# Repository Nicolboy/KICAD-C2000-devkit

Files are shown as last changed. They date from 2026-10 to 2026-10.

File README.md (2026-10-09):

# KICAD-C2000-devkit

Shield d'isolation et cartes devkit pour TMS320 C2000, conçus sous KiCad 10.
Le brochage est décrit en Markdown, les symboles et les projets KiCad en sont
**générés** — le document reste la source de vérité, pas le schéma.

Cible : une commande numérique de convertisseur de puissance isolé, pilotée par
un C2000 et supervisée par un ESP32-C6 pour le Wi-Fi et la mise à jour FOTA.

<p align="center">
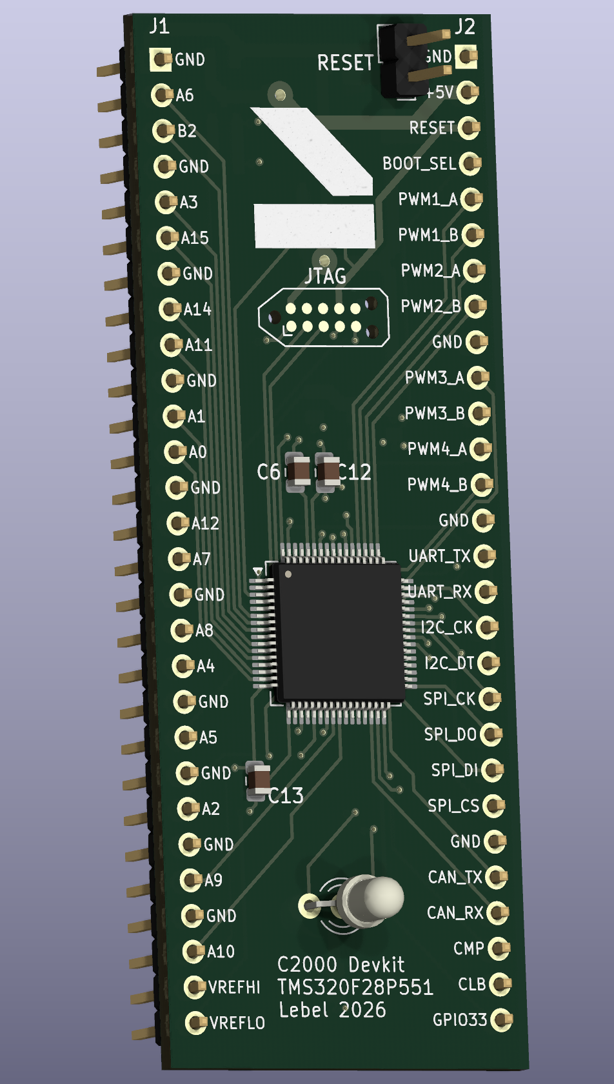
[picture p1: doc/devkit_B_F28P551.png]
Rendu 3D de la carte Devkit TMS320F28P551-LQFP64
  
</p>

---

## Architecture — quatre cartes, une barrière

| Carte | Rôle |
|---|---|
| **Puissance** | Conversion, barrière d'isolation, isolateurs (AMC0311S, AMC0300R, ISO7710, DPC817), shunts en connexion Kelvin, régulateurs |
| **Shield** | Support mécanique des deux devkits, adaptation de brochage, conditionnement analogique, protections. **Aucun composant isolé** |
| **Devkit C2000** | MCU, deux LDO 3,3 V, JTAG, bouton reset, LED, cavalier de boot |
| **Devkit ESP32** | Wi-Fi, hôte FOTA, écran OLED en SPI |

L'isolation est entièrement confinée à la carte de puissance. Le shield ne fait
que du conditionnement côté froid : c'est ce qui permet de le fabriquer en
2 couches à la maison sans se poser de question de ligne de fuite.

Liaison shield ↔ puissance : quatre nappes 2 × 8 à **alternance signal / masse
stricte 1:1**, aucune alimentation dedans. Le +5 V passe par un connecteur
séparé — les 500 mA de la commande n'ont pas à partager leur retour avec les
masses de référence des voies ADC.

---

## Le point de conception le plus notable

**Le connecteur est identique à 100 % entre le F280037 et le F28P551**, 56
positions sur 56. Les deux devkits sont interchangeables sur le shield.

Ce n'est pas une coïncidence, c'est le résultat d'un arbitrage : les LED ont été
délibérément posées sur les **entrées/sorties non communes** aux deux boîtiers,
pour que toutes les broches qui traversent le connecteur, elles, soient
communes. Les quatre divergences restent locales à la carte devkit :

| Broche | F280037 | F28P551 |
|---|---|---|
| 27 | VDD 1,2 V | LED bleue (GPIO20) |
| 28 | VDDIO 3,3 V | LED rouge (GPIO21) |
| 40 | LED rouge (GPIO32) | pastille de test |
| 46 | LED bleue (GPIO39) | VREGENZ à VSS |

La cause profonde est le régulateur 1,2 V : le F28P551 a le sien en interne,
activé par VREGENZ à VSS ; le F280037 en 64 PM non-Q n'a pas cette broche et
demande un LDO supplémentaire.

---

## Le brochage est du code

Le fichier [`doc/spec-devkit.md`](doc/spec-devkit.md) fait autorité. Les
symboles KiCad, les schémas et les vérifications en découlent par génération —
on ne modifie jamais un `.kicad_sym` à la main.

```
doc/spec-devkit.md            source de vérité, relue par un humain
        │
        ├── gen_symbole_mcu.py   → build/C2000_MCU_LQFP64.kicad_sym
        │                          (dimensionne le symbole depuis les noms)
        │
        └── gen_devkit.py        → devkit_A_F280037.*  devkit_B_F28P551.*
              ▲                    kicad_gen.py — primitives communes
              │
            src/*.kicad_sch        schémas source des devkits, versionnés

shield.*                       édité à la main dans KiCad — pas généré
```

L'intérêt n'est pas le gain de temps, c'est que **les règles de conception
deviennent exécutables**. Les générateurs vérifient ce que le document promet :
unicité des broches et des GPIO, masse de part et d'autre des voies de mesure de
courant, présence des réserves. Une divergence entre l'intention et le schéma
est une erreur de script, pas un oubli qu'on découvre au routage.

`gen_symbole_mcu.py` dimensionne par exemple le corps du symbole à partir de la
longueur réelle du nom de broche le plus long, pour que les textes des quatre
faces ne se croisent jamais — plutôt qu'une taille choisie à l'œil qui casse au
premier nom un peu long.

Les schémas ne contiennent d'ailleurs **aucun fil** : toute la connectivité
passe par des étiquettes globales posées sur le point de connexion de chaque
broche. C'est ce qui permet d'ajouter un composant par script sans rien router.

---

## Concevoir avec un agent

Une part inhabituelle du travail est faite par un agent : lire les datasheets,
en extraire les contraintes, écrire la spécification, générer les symboles,
poser les composants et choisir les boîtiers. **Le placement et le routage
restent manuels** — ils encodent des choix que rien ne devine sur une chaîne de
mesure de courant.

[`doc/methode-kicad-claude.md`](doc/methode-kicad-claude.md) documente cette
façon de travailler : le partage des rôles, le déroulé d'une séance, et surtout
les pièges de format rencontrés — chacun avec sa signature, parce que KiCad
répond « échec du chargement » et rien de plus quand un fichier est malformé.

---

## Projets KiCad

Trois, pas un de plus.

| Projet | Contenu |
|---|---|
| `shield.*` | Shield, connecteurs devkit 2 × 28, quatre nappes, ESP32-C6 |
| `devkit_A_F280037.*` | Devkit TMS320F280037CSPM |
| `devkit_B_F28P551.*` | Devkit TMS320F28P551SG5PM |

---

## Reproduire

KiCad 10 et Python 3.12 requis. `kicad-cli` doit être dans le `PATH`.

```bash
python gen_symbole_mcu.py -o build/     # symboles MCU
python gen_devkit.py --force            # les deux projets devkit

kicad-cli sch erc --exit-code-violations <projet>.kicad_sch
kicad-cli pcb drc --exit-code-violations <projet>.kicad_pcb
```

`shield.*` n'apparaît pas ici : il est édité à la main et ne se régénère pas.
Les schémas de devkit produits à la racine sont en revanche **jetables** — toute
retouche manuelle y est perdue au prochain `--force`. Ce qui doit survivre se
modifie dans `src/` ou dans le générateur.

Chaque carte existe en **deux versions de fabrication** : 2 couches gravées à
la maison — pistes 1 mm, vias 2 mm, perçage 0,8 mm — pour itérer vite sur la
mécanique, et 4 couches en fabrication externe, avec plan de masse continu sous
la zone analogique. Même schéma, même brochage, seul le PCB change.

---

## État d'avancement

Travail en cours, et le dire plutôt que de le masquer :

- **Devkit B (F28P551)** — **PCB placé et routé** (24 empreintes, DRC à 0
  violation). Les deux connecteurs 2 × 28 portent désormais une sérigraphie
  par broche — canal ADC réel, GPIO, rôle de bus générique (`I2C_CK`/`DT`,
  `SPI_CK`/`DO`/`DI`/`CS`...) et alimentations, plutôt que les noms
  spécialisés du schéma (`Vin`, `I_SHUNT1_CMP`...), pour que le connecteur se
  lise seul. L'ERC du schéma reste à 41 violations, de la même famille que
  les autres projets (pins de réserve non pilotées).
- **Devkit A (F280037)** — PCB **peuplé** (27 empreintes posées depuis le
  schéma) mais pas encore routé : 106 pastilles non connectées au DRC.
- **Shield** — connecteurs posés, alimentations câblées avec `PWR_FLAG` par
  net. Le routage des signaux n'est pas fait : il demande des choix de
  conception qui n'ont pas leur place dans un générateur. D'où les 108
  violations d'ERC (`pin_not_connected` attendus). PCB non routé.
- **Carte de puissance** — spécifiée dans `doc/`, pas encore dessinée.

Les points laissés ouverts — caractéristiques de sortie des AMC, courant
d'entrée du REFIN, choix de VREFHI — sont listés en fin de
[`doc/decisions.md`](doc/decisions.md). Ils attendent une lecture de datasheet,
pas une estimation.

---

## Décisions à ne pas défaire

Certains choix ressemblent à des inefficacités sans en être. Les douze sont
documentés dans [`doc/decisions.md`](doc/decisions.md), chacun avec sa raison et
ce qui casse si on le défait — entre autres :

- Les **PWM3 et PWM4 restent en réserve et restent des PWM** : ce sont les deux
  seules paires complémentaires HRPWM avec temps mort matériel disponibles.
- Chaque shunt sort **deux fois**, `_MES` filtré et `_CMP` direct. Le chemin
  comparateur attaque le CMPSS sans filtre anti-repliement : pas de retard sur
  le déclenchement de la Trip Zone, et un défaut du filtre ne désarme pas la
  protection.
- Les **16 voies ADC sortent toutes** pour 9 nécessaires, les 5 libres étant
  câblées jusqu'aux réserves de nappe. Une voie ajoutée plus tard se raccorde
  sans retoucher une seule carte.

---

## Licence

[CERN-OHL-S v2](LICENSE) — CERN Open Hardware Licence, fortement réciproque.

Tu peux étudier, modifier, fabriquer et distribuer ce matériel. En contrepartie,
si tu distribues un produit fondé dessus, ou une version modifiée, tu dois
publier les sources correspondantes sous la même licence.

C'est la licence de référence du matériel libre, l'équivalent de la GPL côté
logiciel. Si tu préfères une réciprocité limitée à la carte elle-même, ou pas de
réciprocité du tout, les variantes CERN-OHL-W et CERN-OHL-P existent.

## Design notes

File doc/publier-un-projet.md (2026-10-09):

# Publier un projet sur GitHub — mémo et prompt

Mémo de poste à poste. Ce qui suit vient de pièges réels, pas d'une liste de
bonnes pratiques générales.

---

## Un poste, une clé

**Une clé privée ne voyage pas.** Copiée sur une clé USB ou envoyée par
messagerie, elle devient une copie qu'on ne contrôle plus, et on perd la
capacité de révoquer un seul poste sans casser les autres.

GitHub accepte autant de clés de compte que l'on veut. Sur un nouveau poste :

```bash
ssh-keygen -t ed25519 -C "contact@nicolasboyer.fr" -f ~/.ssh/github_<poste>
cat ~/.ssh/github_<poste>.pub        # à coller sur github.com/settings/keys
```

Puis dans `~/.ssh/config` :

```
Host github.com
    HostName github.com
    User git
    IdentityFile ~/.ssh/github_<poste>
    IdentitiesOnly yes
```

**Vérification qui compte** : `ssh -T git@github.com` doit répondre
`Hi Nicolboy!`. S'il répond un **nom de dépôt**, c'est une clé de
*déploiement* — limitée à ce dépôt, et inutilisable ailleurs. Une clé de
déploiement survit d'ailleurs quelque temps à la suppression de son dépôt, et
bloque alors sa propre réutilisation avec un « key already in use » déroutant.

**Piège associé** : un `core.sshCommand` dans le `.git/config` d'un dépôt
court-circuite `~/.ssh/config` et impose une autre clé. Symptôme : `ssh -T`
réussit, `git push` échoue avec « denied to deploy key ».

```bash
git config --local --unset core.sshCommand
```

---

## Prompt de migration

À coller dans Claude Code sur le poste concerné.

```
Je veux publier mes projets de ce poste sur GitHub, compte Nicolboy.
Procède projet par projet, dans cet ordre, et arrête-toi à chaque décision.

1. INVENTAIRE
   Liste les dossiers de projet, leur taille, s'ils sont déjà sous git,
   et ce qu'ils contiennent. Ne touche à rien pour l'instant.
   Dis-moi lesquels te semblent publiables et lesquels ne le sont pas.

2. CE QUI BLOQUE UNE PUBLICATION — vérifie-le avant tout le reste
   - Datasheets et documents constructeur : SOUS COPYRIGHT, jamais
     redistribuables. Cherche tous les PDF, y compris dans l'historique git.
     S'ils sont déjà commités, un `git rm` ne suffit pas : un clone les
     rapatrierait. Il faut purger l'historique.
     À la place, écris un docs/references.md avec les références exactes
     et où les télécharger chez le fabricant.
   - Secrets : clés, jetons, mots de passe, SSID. Cherche aussi dans
     l'historique.
   - Code tiers : SDK, bibliothèques fabricant. Ne les réécris pas et ne
     retire jamais leurs en-têtes de copyright — c'est la condition qui rend
     leur redistribution légale. Dis-moi sous quelle licence ils sont.

3. PRÉPARATION
   - .gitignore : binaires, dossiers de build, config locale d'IDE,
     outillage d'agent (.claude/, .codex/), *.pdf
   - README : ce que fait le projet, son architecture, son ÉTAT RÉEL —
     y compris ce qui ne marche pas encore. Pas de liste de fonctionnalités.
   - LICENSE : demande-moi laquelle. CERN-OHL-S pour du matériel,
     MIT ou Apache-2.0 pour du logiciel.
   - Vérifie que la branche par défaut porte bien le travail à jour.
     Une branche `main` abandonnée pendant que tout vit ailleurs est un
     piège classique : GitHub affiche `main`.

4. AVANT DE POUSSER
   - Commite d'abord tout ce qui traîne non sauvegardé, avec de vrais
     messages qui disent POURQUOI, pas quoi.
   - Fais une sauvegarde : git bundle create ../<nom>.bundle --all
   - Propose-moi un nom de dépôt et attends ma validation.
   - Ne pousse jamais sans me demander.

Règles générales : commite avant toute modification. Si tu trouves une
incohérence entre la documentation et le code, signale-la, ne la corrige
pas d'office.
```

---

## D'où viennent ces points

| Point | Ce qui s'est passé |
|---|---|
| PDF dans l'historique | 13 Mo de documents TI, **95 % du poids** du dépôt firmware. Purgés : 12 Mo → 579 Ko |
| Branche par défaut | `main` figée depuis six semaines pendant que 51 commits vivaient sur `bringup`. GitHub aurait affiché la vieille |
| Commiter d'abord | une modification substantielle non sauvegardée a failli disparaître dans la réécriture d'historique |
| Clé de déploiement | authentifiait, mais refusait de pousser vers un autre dépôt que le sien |
| Licence du code tiers | les fichiers C2000Ware sont sous BSD 3 clauses : redistribuables, **à condition** de garder les en-têtes |

---

## Conventions de nommage

Les dépôts publiés suivent `<OUTIL>-<CIBLE>-<sujet>` :

- `KICAD-C2000-devkit`
- `CCS-C2000-hv-boost`

Un visiteur du profil voit la paire et comprend que l'un est le matériel et
l'autre ce qui tourne dessus. La partie descriptive reste en minuscules avec
des tirets.

**Un nom n'est pas un engagement** : un renommage GitHub conserve l'historique,
les issues et les étoiles, et installe une redirection permanente depuis
l'ancienne URL.

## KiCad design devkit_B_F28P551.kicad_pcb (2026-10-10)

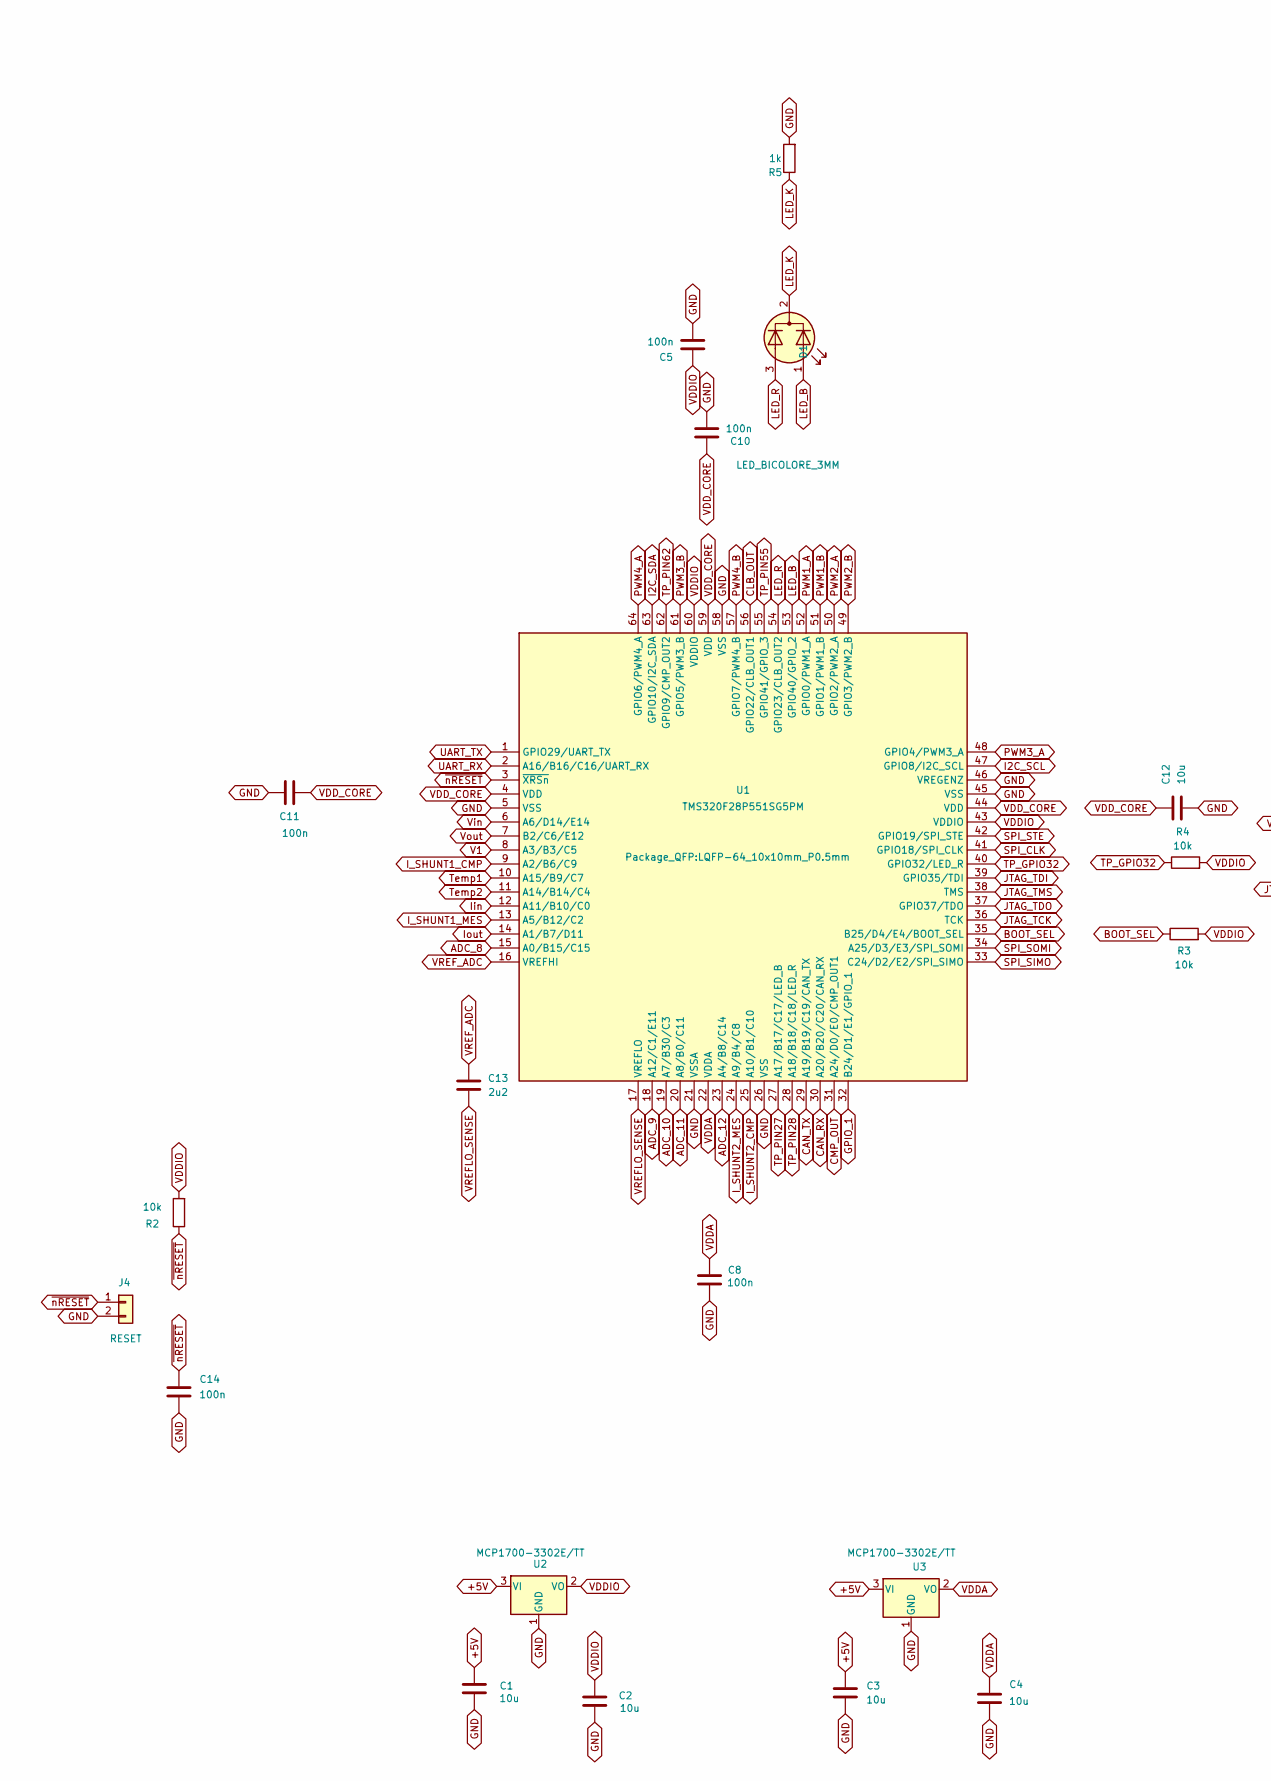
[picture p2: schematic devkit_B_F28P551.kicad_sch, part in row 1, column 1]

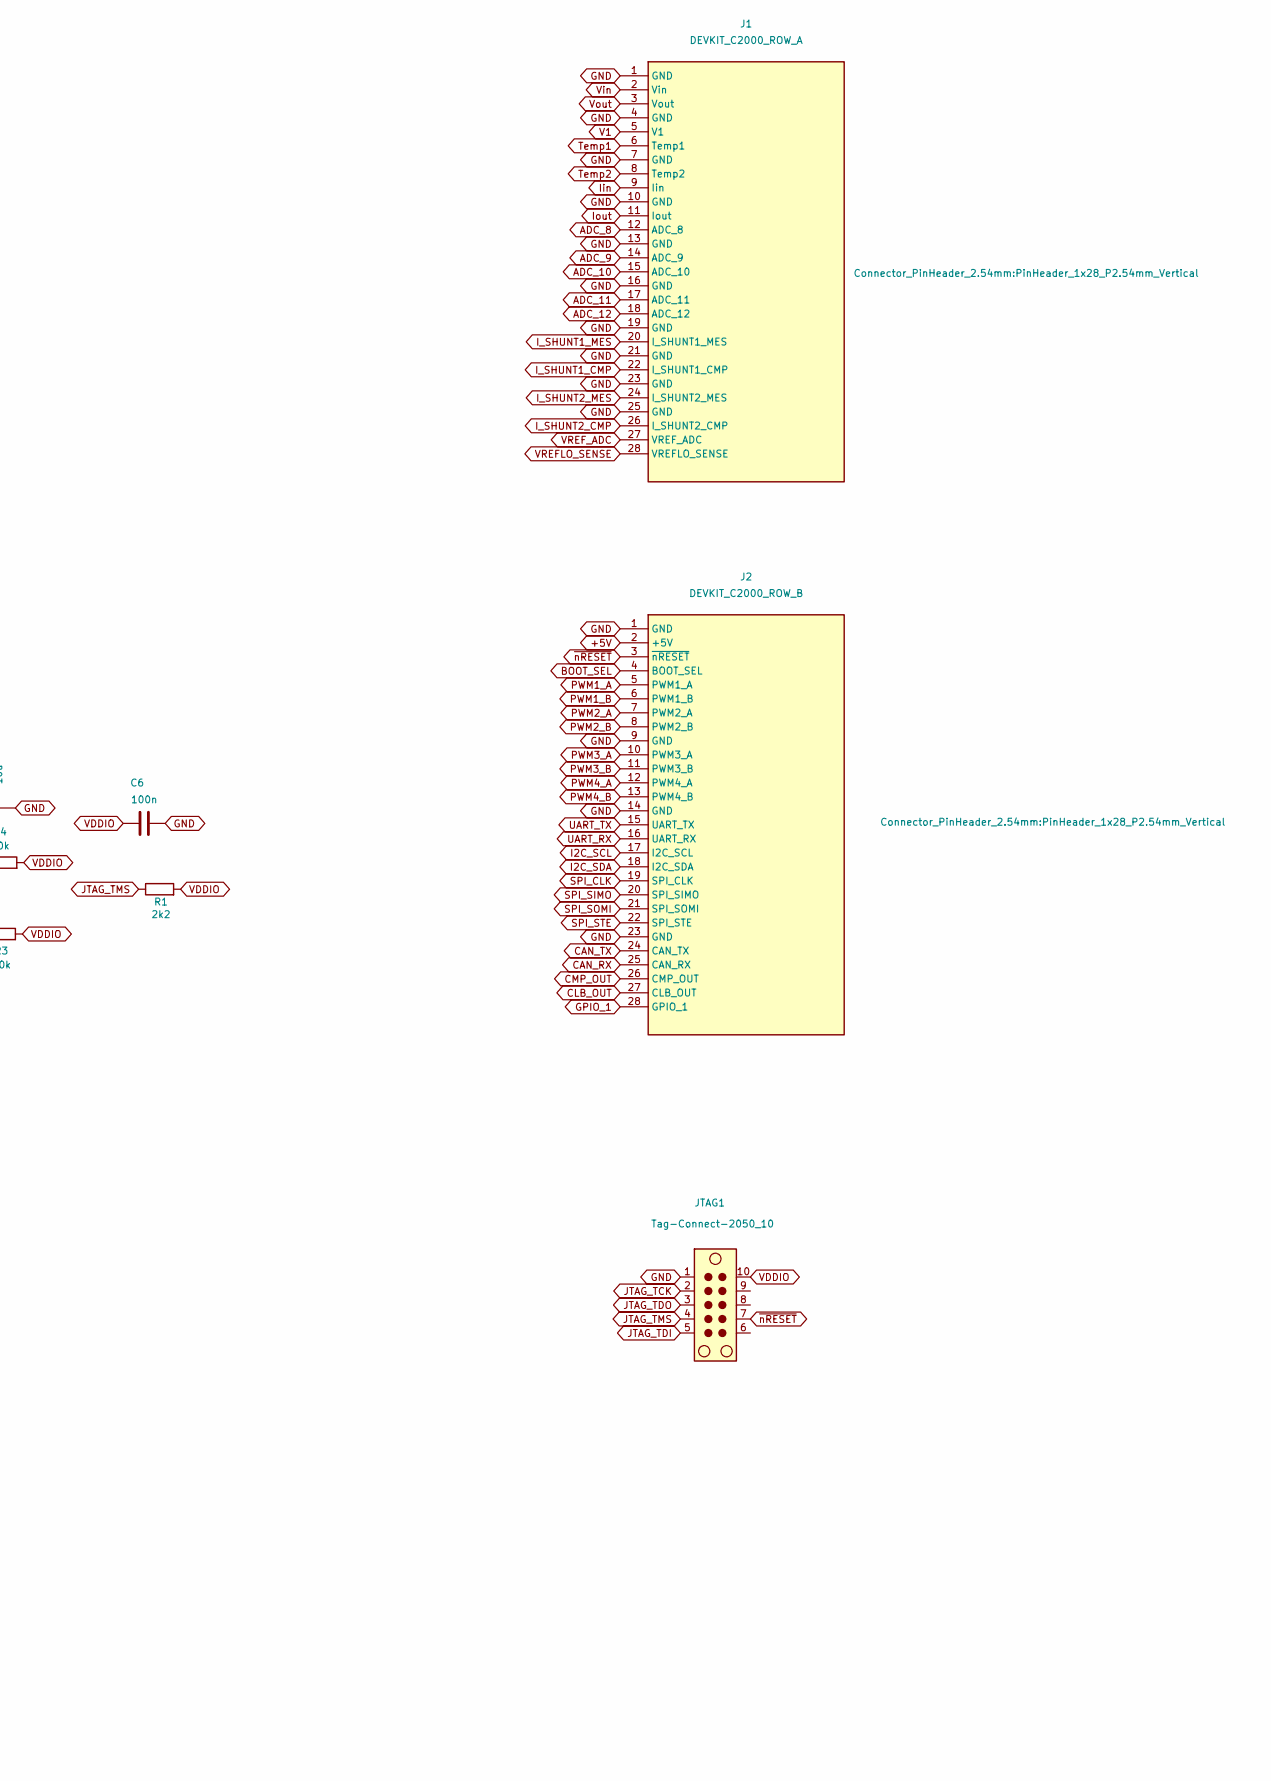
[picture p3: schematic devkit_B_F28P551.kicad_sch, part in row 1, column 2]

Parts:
C1, C2, C3, C4, C12: 10u; C_0805_2012Metric
C5, C6, C8, C10, C11, C14: 100n; C_0805_2012Metric
C13: 2u2; C_0805_2012Metric
D1: LED_BICOLORE_3MM; LED_D3.0mm-3
J1: DEVKIT_C2000_ROW_A; PinHeader_1x28_P2.54mm_Vertical
J2: DEVKIT_C2000_ROW_B; PinHeader_1x28_P2.54mm_Vertical
J4: RESET; PinHeader_1x02_P2.54mm_Vertical
JTAG1: Tag-Connect-2050_10; Tag-Connect_TC2050-IDC-NL_2x05_P1.27mm_Vertical
R1: 2k2; R_0805_2012Metric
R2, R3, R4: 10k; R_0805_2012Metric
R5: 1k; R_0805_2012Metric
U1: TMS320F28P551SG5PM; LQFP-64_10x10mm_P0.5mm
U2, U3: MCP1700-3302E/TT; SOT-23

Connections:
+5V: C1.1, C3.1, J2.2 (+5V), U2.3 (VI), U3.3 (VI)
ADC_8: J1.12 (ADC_8), U1.15 (A0/B15/C15)
ADC_9: J1.14 (ADC_9), U1.18 (A12/C1/E11)
ADC_10: J1.15 (ADC_10), U1.19 (A7/B30/C3)
ADC_11: J1.17 (ADC_11), U1.20 (A8/B0/C11)
ADC_12: J1.18 (ADC_12), U1.23 (A4/B8/C14)
BOOT_SEL: J2.4 (BOOT_SEL), R3.1, U1.35 (B25/D4/E4/BOOT_SEL)
CAN_RX: J2.25 (CAN_RX), U1.30 (A20/B20/C20/CAN_RX)
CAN_TX: J2.24 (CAN_TX), U1.29 (A19/B19/C19/CAN_TX)
CLB_OUT: J2.27 (CLB_OUT), U1.56 (GPIO22/CLB_OUT1)
CMP_OUT: J2.26 (CMP_OUT), U1.31 (A24/D0/E0/CMP_OUT1)
GND: C1.2, C2.2, C3.2, C4.2, C5.2, C6.2, C8.2, C10.2, C11.2, C12.2, C14.2, J1.1 (GND), J1.4 (GND), J1.7 (GND), J1.10 (GND), J1.13 (GND), J1.16 (GND), J1.19 (GND), J1.21 (GND), J1.23 (GND), J1.25 (GND), J2.1 (GND), J2.9 (GND), J2.14 (GND), J2.23 (GND), J4.2, JTAG1.1, R5.2, U1.5 (VSS), U1.21 (VSSA), U1.26 (VSS), U1.45 (VSS), U1.46 (VREGENZ), U1.58 (VSS), U2.1 (GND), U3.1 (GND); also elsewhere on the board
GPIO_1: J2.28 (GPIO_1), U1.32 (B24/D1/E1/GPIO_1)
I2C_SCL: J2.17 (I2C_SCL), U1.47 (GPIO8/I2C_SCL)
I2C_SDA: J2.18 (I2C_SDA), U1.63 (GPIO10/I2C_SDA)
I_SHUNT1_CMP: J1.22 (I_SHUNT1_CMP), U1.9 (A2/B6/C9)
I_SHUNT1_MES: J1.20 (I_SHUNT1_MES), U1.13 (A5/B12/C2)
I_SHUNT2_CMP: J1.26 (I_SHUNT2_CMP), U1.25 (A10/B1/C10)
I_SHUNT2_MES: J1.24 (I_SHUNT2_MES), U1.24 (A9/B4/C8)
Iin: J1.9 (Iin), U1.12 (A11/B10/C0)
Iout: J1.11 (Iout), U1.14 (A1/B7/D11)
JTAG_TCK: JTAG1.2, U1.36 (TCK); also elsewhere on the board
JTAG_TDI: JTAG1.5, U1.39 (GPIO35/TDI); also elsewhere on the board
JTAG_TDO: JTAG1.3, U1.37 (GPIO37/TDO); also elsewhere on the board
JTAG_TMS: JTAG1.4, R1.1, U1.38 (TMS); also elsewhere on the board
LED_B: D1.1 (A1), U1.53 (GPIO40/GPIO_2)
LED_K: D1.2 (K), R5.1
LED_R: D1.3 (A2), U1.54 (GPIO23/CLB_OUT2)
PWM1_A: J2.5 (PWM1_A), U1.52 (GPIO0/PWM1_A)
PWM1_B: J2.6 (PWM1_B), U1.51 (GPIO1/PWM1_B)
PWM2_A: J2.7 (PWM2_A), U1.50 (GPIO2/PWM2_A)
PWM2_B: J2.8 (PWM2_B), U1.49 (GPIO3/PWM2_B)
PWM3_A: J2.10 (PWM3_A), U1.48 (GPIO4/PWM3_A)
PWM3_B: J2.11 (PWM3_B), U1.61 (GPIO5/PWM3_B)
PWM4_A: J2.12 (PWM4_A), U1.64 (GPIO6/PWM4_A)
PWM4_B: J2.13 (PWM4_B), U1.57 (GPIO7/PWM4_B)
SPI_CLK: J2.19 (SPI_CLK), U1.41 (GPIO18/SPI_CLK)
SPI_SIMO: J2.20 (SPI_SIMO), U1.33 (C24/D2/E2/SPI_SIMO)
SPI_SOMI: J2.21 (SPI_SOMI), U1.34 (A25/D3/E3/SPI_SOMI)
SPI_STE: J2.22 (SPI_STE), U1.42 (GPIO19/SPI_STE)
TP_GPIO32: R4.1, U1.40 (GPIO32/LED_R)
TP_PIN27: U1.27 (A17/B17/C17/LED_B)
TP_PIN28: U1.28 (A18/B18/C18/LED_R)
TP_PIN55: U1.55 (GPIO41/GPIO_3)
TP_PIN62: U1.62 (GPIO9/CMP_OUT2)
Temp1: J1.6 (Temp1), U1.10 (A15/B9/C7)
Temp2: J1.8 (Temp2), U1.11 (A14/B14/C4)
UART_RX: J2.16 (UART_RX), U1.2 (A16/B16/C16/UART_RX)
UART_TX: J2.15 (UART_TX), U1.1 (GPIO29/UART_TX)
V1: J1.5 (V1), U1.8 (A3/B3/C5)
VDDA: C4.1, C8.1, U1.22 (VDDA), U3.2 (VO)
VDDIO: C2.1, C5.1, C6.1, JTAG1.10, R1.2, R2.2, R3.2, R4.2, U1.43 (VDDIO), U1.60 (VDDIO), U2.2 (VO); also elsewhere on the board
VDD_CORE: C10.1, C11.1, C12.1, U1.4 (VDD), U1.44 (VDD), U1.59 (VDD)
VREFLO_SENSE: C13.2, J1.28 (VREFLO_SENSE), U1.17 (VREFLO)
VREF_ADC: C13.1, J1.27 (VREF_ADC), U1.16 (VREFHI)
Vin: J1.2 (Vin), U1.6 (A6/D14/E14)
Vout: J1.3 (Vout), U1.7 (B2/C6/E12)
~nRESET: C14.1, J2.3 (~nRESET), J4.1, JTAG1.7, R2.1, U1.3 (~XRSn); also elsewhere on the board

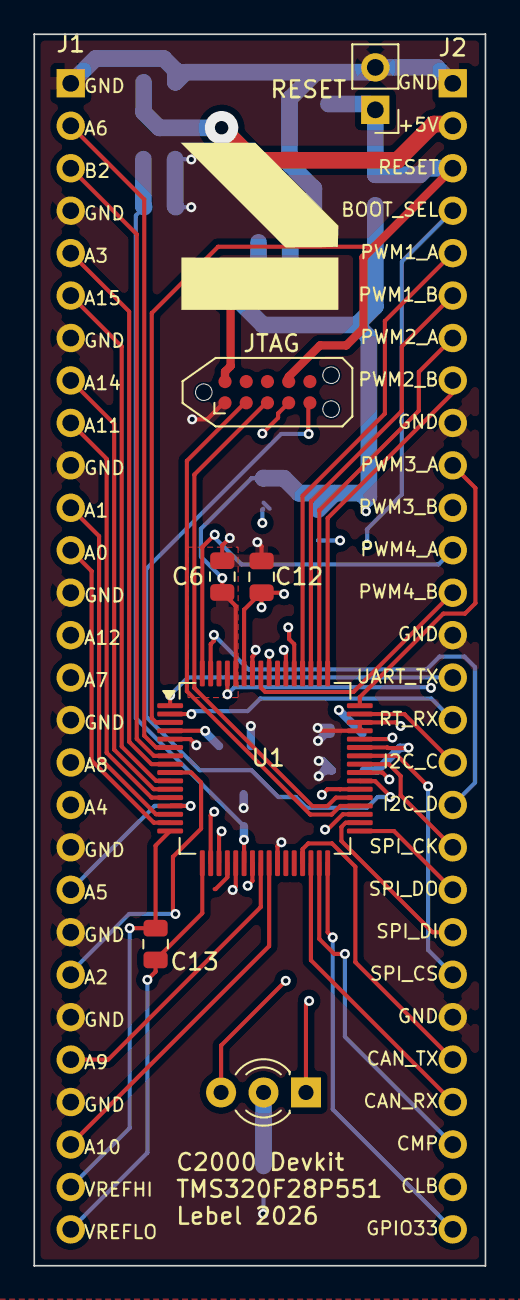
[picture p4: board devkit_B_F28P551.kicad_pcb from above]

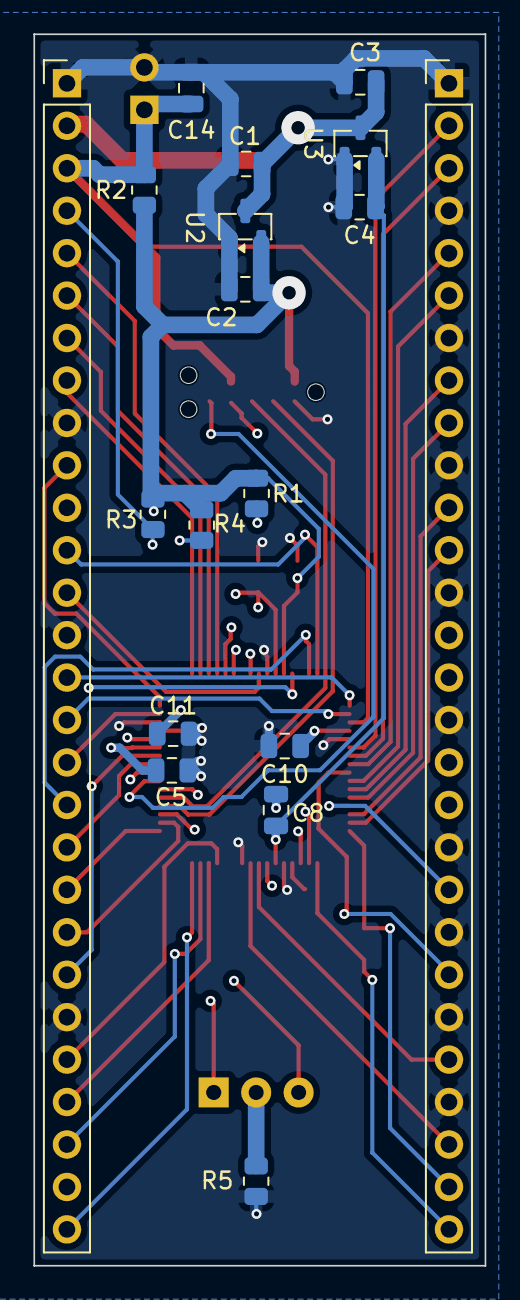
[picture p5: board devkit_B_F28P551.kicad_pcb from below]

Board: 4 copper layers, 27.0 x 73.7 mm, 25 parts (18 on the bottom side), 54 nets.

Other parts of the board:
JTAG: Tag-Connect-2050_10; Tag-Connect_TC2050-IDC-NL_2x05_P1.27mm_Vertical

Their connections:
GND: JTAG.1; also elsewhere on the board
JTAG_TCK: JTAG.2; also elsewhere on the board
JTAG_TDI: JTAG.5; also elsewhere on the board
JTAG_TDO: JTAG.3; also elsewhere on the board
JTAG_TMS: JTAG.4; also elsewhere on the board
VDDIO: JTAG.10; also elsewhere on the board
~nRESET: JTAG.7; also elsewhere on the board

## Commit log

2026-09-28 Memo de publication GitHub, transferable d'un poste a l'autre
    Travailler depuis plusieurs postes demande que ces indications suivent le
    projet plutot que la machine. Le memo rassemble ce qui a reellement coince:
    - une cle privee ne voyage pas: une par poste, ajoutee au compte. Avec le
    symptome qui distingue une cle de deploiement d'une cle de compte, et le
    core.sshCommand local qui court-circuite ~/.ssh/config.
    - le prompt de migration, ordonne, qui fait verifier les bloqueurs AVANT de
    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
2026-10-07 Devkit B routé, sérigraphie des connecteurs 2x28 et logo
    Placement/routage complet du PCB devkit B (24 empreintes, J1/J2 câblés).
    Étiquettes de sérigraphie ajoutées sur les 56 broches des connecteurs
    Row A/Row B (canal ADC réel, GPIO, rôle de bus générique, alimentations)
    via kipy sur l'instance ouverte, plutôt que les noms spécialisés du
    schéma. Logo ajouté (lib/lebel-logo) et fp-lib-table versionné.
    [devkit_B_F28P551.kicad_pcb, devkit_B_F28P551.kicad_sch]
2026-10-07 Corrige le chevauchement silkscreen/cuivre sur UART_RX
    Etiquette raccourcie en RT_RX et clearance JTAG/masse resolue :
    DRC propre (0 violation).
    [devkit_B_F28P551.kicad_pcb]
2026-10-07 Met a jour l'avancement du README par carte
    Devkit B route et DRC propre, sa serigraphie de connecteurs, devkit A
    peuple mais pas route (106 pastilles), shield inchange - chiffres ERC/DRC
    revérifiés sur les trois projets plutot que l'ancien statut global perime.
2026-10-09 Renomme les references au depot (KICAD-C2000-shield -> KICAD-C2000-devkit), suite a jour sur devkit_B_F28P551
    Met a jour CLAUDE.md, README.md et doc/publier-un-projet.md apres le
    renommage du depot GitHub. devkit_B_F28P551.kicad_pcb reflete le travail
    de routage en cours.
    [devkit_B_F28P551.kicad_pcb]
2026-10-10 Ajuste le preset de via a 0.6/0.3mm et resauvegarde le PCB
    Changement de reglage de projet (diametre de via 0.5->0.6mm, meme percage),
    plus la resauvegarde associee du PCB par KiCad (zones de cuivre regenerees).
    [devkit_B_F28P551.kicad_pcb]
2026-10-10 Allege CLAUDE.md : renvoi vers KICAD.md pour ce qui est deja commun
    Coupe les sections dupliquees avec KICAD.md (edition PCB via kipy, schema
    ferme, verification kicad-cli) et avec doc/publier-un-projet.md (cle SSH).
    KICAD.md absorbe les 3 regles qui etaient repetees dans chaque CLAUDE.md
    de projet (commit avant modif, headless, export via kicad-cli uniquement).
2026-10-14 devkit_B_F28P551 : rangee A reroutee pour le CLB (Stage1_EN/Stage2_EN/HV_EN/Discharge), documentation rattrapee
    Carte figee, production-ready, modifiee malgre la regle habituelle (decision
    explicite de l'utilisateur) : miroir de la decision #20 du depot
    KICAD-C2000-powershield cote devkit.
    - Rangee A reroutee : Stage1_EN (A23, broche 62/GPIO9), Stage2_EN (A24,
    broche 27/GPIO20), HV_EN (A25, broche 28/GPIO21), Discharge (A26, broche
    55/GPIO41) - six masses pour vingt-deux signaux au lieu de dix pour
    dix-huit.
    - Rangee B : nRESET -> ~{RESET} (B3), GPIO_1 -> ~{FAULT_MCU} (B28), logique
    negative, meme net.
    - devkit_A_F280037 non modifie (CLB absent du F280037) : le connecteur
    n'est pl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
2026-10-14 Consigne le plan v2 du connecteur devkit (4 connecteurs 1x24, masse en vis-a-vis)
    Proposition non construite, issue de la discussion suite a la decision #13 :
    la rangee A de devkit_B n'a plus que six masses pour vingt-deux signaux. Le
    plan documente la cible (deux connecteurs 1x24 par domaine, dephases
    signal/masse), ce qui reste ouvert (detrompage intra-domaine) et les etapes
    avant de router quoi que ce soit.
2026-10-18 Ajoute le connecteur RKB2SJM250SMTR_LFS et partage TO252
    - Connecteur RKB2SJM250SMTR_LFS (lib + modele 3D) integre au connecteur
    devkit, modification de brochage associee (modificatio_brochage_devkit)
    -- travail deja en place localement, jamais commite.
    - fp-lib-table : empreinte TO252 partagee enregistree
    (lib_fp_commun/TO252.pretty, voir KICAD.md), pas encore utilisee par
    un composant de ce depot.
2026-11-01 Retire le tableau errone des 4 divergences de broches F280037/F28P551
    Le detail (VDD 1,2V/VDDIO/VREGENZ par broche) et l'explication sur le
    regulateur interne etaient faux. Le constat qui reste (connecteur
    identique a 100%, LED posees sur les I/O non communes) est correct.
2026-11-10 Ajoute VDDIO/GND sur J1 broches 47/48, corrige le frein thermique, logo vers lib partagee
    Les deux broches NC du connecteur DEVKIT_C2000_A (47/48) portent
    desormais VDDIO et GND (alternance masse/signal respectee, cote gauche
    GND cote droit signal), pour servir de reference aux pull-up I2C du
    powershield. Meme changement reporte dans la bibliotheque partagee
    C2000_Devkit_Connectors.kicad_sym.
    Corrige aussi 18 erreurs DRC starved_thermal (masses intercalees entre
    signaux sur grille 2,54mm, 1 seul rayon disponible par pastille) en
    abaissant min_resolved_spokes a 1 et min_clearance a 0,5mm.
    Logo lebel bascule vers la bibliotheque partagee lib_fp_commun au lieu
    d'une copie locale.
    Co-Authored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
2026-11-11 README : Devkit B "routé a 100%", decompte des decisions a jour (12->13)
2026-11-11 ERC devkit_B : 10 erreurs -> 0
    - pin_to_pin (2) : broches VDD du MCU typees power_out au lieu de
    power_in dans lib/C2000_MCU.kicad_sym (erreur isolee - VDDA, VDDIO,
    VSS, VSSA etaient deja correctes). Corrige dans la bibliotheque
    source + cache embarque devkit_B ; cache embarque devkit_A
    resynchronise aussi (meme bibliotheque, meme erreur sur ses propres
    VDD) pour eviter un nouveau lib_symbol_mismatch - ERC complet de
    devkit_A pas refait, hors perimetre de cette demande.
    - power_pin_not_driven (3, dont VDD_CORE revele par le fix ci-dessus -
    regulateur interne du MCU, VREGENZ->VSS confirme par
    doc/spec-devkit.md) + pin_not_driven (3, signaux fournis par le
    shield externe, J1/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
